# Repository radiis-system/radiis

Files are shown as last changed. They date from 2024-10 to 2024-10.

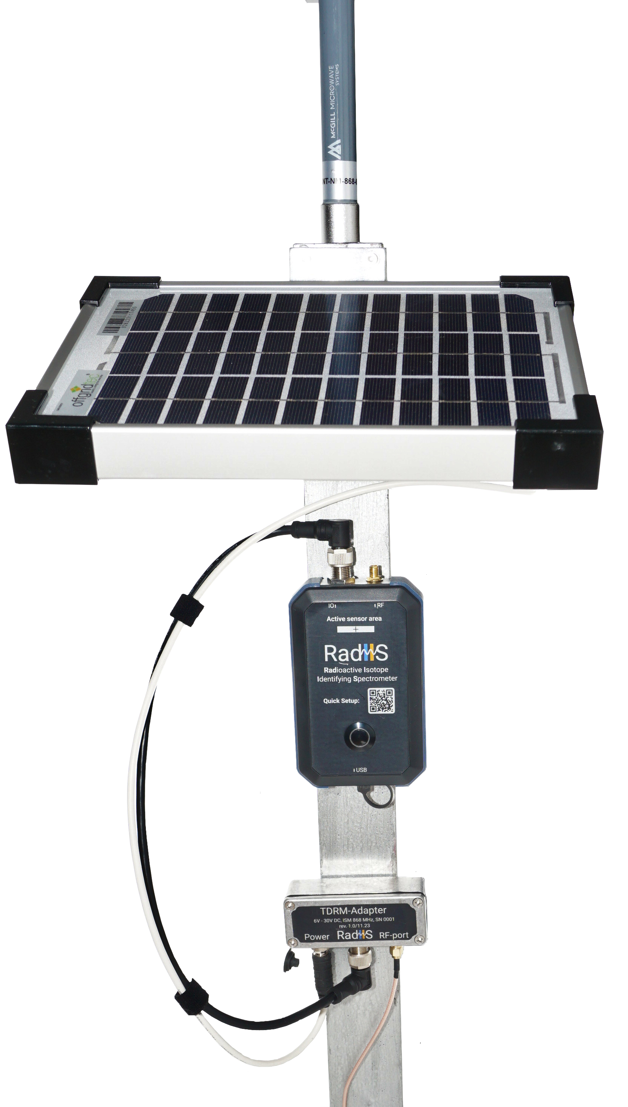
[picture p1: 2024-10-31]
Documentation/Pictures/RadIIS_Station.png

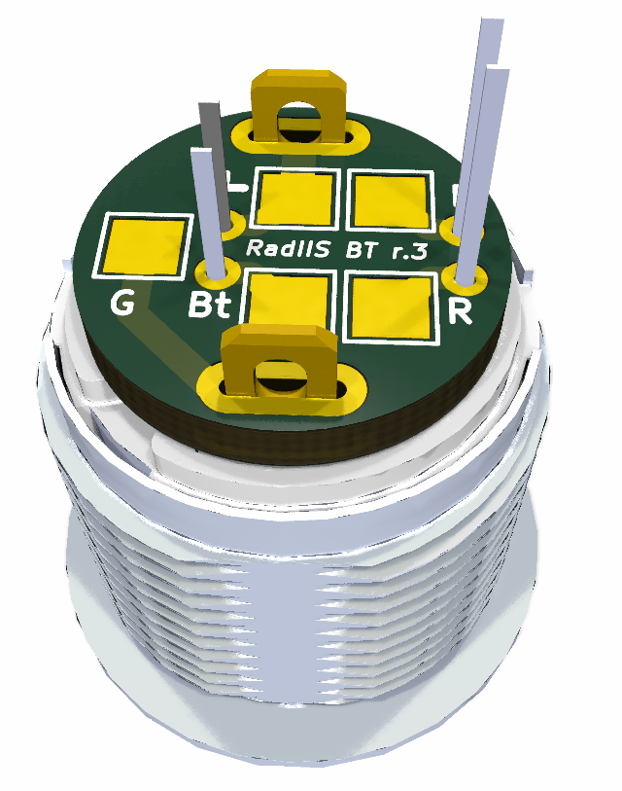
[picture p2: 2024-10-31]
Documentation/Pictures/BUTTON_PCB.png

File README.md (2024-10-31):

# RadIIS - the Radioactive Isotope Identifying Spectrometer

RadIIS is an open-source and industrial grade gamma spectrometer with automatic isotope identification.


It can be used as a handheld device, connected to a mobile phone (or tablet, pc, …) or as a monitoring station with backup battery, wide-range power input and long-range data transfer (LoRa).

> [!NOTE]
> This repository is currently transferred from a private repository. As different licenses for numerous files must be respected, this takes some time. Please stay tuned

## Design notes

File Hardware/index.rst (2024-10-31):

Hardware
==================================

documentation of the hardware side of RadIIS:

Mainboard
-----------

 `Mainboard BOM <../_static/ibom.html>`_

.. toctree::
   :maxdepth: 2
   :caption: Hardware:

    Hardware/index

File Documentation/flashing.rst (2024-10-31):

.. _flashing-label:

Programming
==================================

As RadIIS contains two microcontroller (STM32L476 and ESP32) the programming via USB is a two step process. Programming of the ESP32 is managed by the STM32 as this controller provides the USB interface.  

For all steps/methods RadIIS needs to be connected via USB to your (linux) computer. You need to be able to send SCPI commands to RadIIS (see :ref:`SCPI-label`).

Simple method (flashRadIIS.py)
-----------

.. TODO: Implement/Document the flashRadIIS.py

Use the provided flashRadIIS.py utility.

Direct programming STM32
-----------

1) Make sure the SCPI communication is working e.g. by requesting the device ID via ``*IDN?`` or check for connection via ``SYS:ACK?``
2) Reset the STM32 and enable the internal bootloader via ``SYStem:BOOTLoader``
3) Flash the firmware via dfu-util: ``dfu-util -a 0 -s 0x08000000:leave -D .pioenvs/RadIIS_STM/firmware.bin``

Direct programming ESP32
-----------

1) Make sure the SCPI communication is working e.g. by requesting the device ID via ``*IDN?`` or check for connection via ``SYS:ACK?``
2) Reset the ESP32, enable its bootloader and make route the USB communication to the ESP via the single command: ``SYStem:ESP:FLASHMode``
3) Flash the firmware via platform-io: ``pio run --target upload``

Internally platform-io uses esptool which can by also used to upload the firmware. 

The internal command is:

``python3 esptool.py --chip esp32 --port "/dev/ttyACM0" --baud 115200 --before default_reset --after hard_reset write_flash -z --flash_mode dio --flash_freq 40m --flash_size detect 0x1000 /home/<USER>/.platformio/packages/framework-arduinoespressif32/tools/sdk/bin/bootloader_dio_40m.bin 0x8000 <PROJECTDIR>/.pio/build/esp32dev/partitions.bin 0xe000 /home/<USER>/.platformio/packages/framework-arduinoespressif32/tools/partitions/boot_app0.bin 0x10000 <PROJECTDIR>/.pio/build/esp32dev/firmware.bin``

See https://docs.espressif.com/projects/esptool/en/latest/esp32/esptool/flashing-firmware.html for further details.

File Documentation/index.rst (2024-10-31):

(Advanced) Usage:
==================================

Advanced usage documentation, e.g. USB SCPI commands or firmware (re)flashing hints.
This part is meant for the advanced user that wishes to use the SCPI interface or to 
flash a custom firmware to the device.

.. toctree::
   :maxdepth: 1
   :caption: Usage:
   
   SCPI
   flashing

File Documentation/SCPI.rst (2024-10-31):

.. _SCPI-label:

SCPI commands
==================================

documentation of the (advanced) usage of RadIIS via SCPI Commands:

.. TODO: Document the connection and (working) serial tools

SYStem:BIAS
-----------
    
Set the SiPM bias, given in [mV]. Higher bias means a higher signal amplification. If a very low bias is set it might be impossible to digitize the signals. It is not possible to choose a bias that damages the system if the enclosure is intact.

The query, SYStem:BIAS?, returns the configured bias voltage in mV.

    | **Command Syntax:** ``SYStem:BIAS <int>``
    | **Parameters:** 24304 mV to 29950 mV
    | **Default:** 27000 mV
    | **Example:** ``SYS:BIAS 26000`` (Sets the bias to 26.00V)
    | **Query Syntax:** ``SYStem:BIAS?``
    | **Return Param:** SiPM bias in mV [int]

SYStem:ATC
-----------

Activates or deactivates the **A** utomatic **T** emperature **C** ompensation. If enabled the bias of the SiPM is automatically adjusted to maintain a constant gain during temperature variations. It is very recommended to acctivate the ATC during measurements.   

The query, SYStem:ATC?, returns the state if the ATC.

    | **Command Syntax:** ``SYStem:ATC <bool>``
    | **Parameters:** 0 (OFF) | 1 (ON)
    | **Default:** 1 (ON)
    | **Example:** ``SYS:ATC ON`` (Activates the ATC)
    | **Query Syntax:** ``SYStem:ATC?``
    | **Return Param:** State of the ATC [bool]

SYStem:TEMPerature?
-----------

Query the sensor (SiPM) temperature in mC.

    | **Query Syntax:** ``SYStem:TEMPerature?``
    | **Return Param:** SiPM temperature in mC [int]

SYStem:BATtery:LEVEL?
-----------
    
Query the internal battery level in mV [int].

    | **Query Syntax:** ``SYStem:BATtery:LEVEL?``
    | **Return Param:** Internal battery level in mV [int]
        
.. function:: SYStem:COMParator:THReshold <INT>
    
    Set the comparator threshold for the external and internal channel. The number is given in DAC counts. Higher numbers mean a higher signal level that is needed to trigger a detection of a pulse. 
    
    *Maximum = 4095*
    *Minimum = 0*
    *Default = 0*
    
    Example: SYS:COMP:THR 100 

.. function:: SYStem:COMParator:THReshold?
    
    *Returns:* Get the comparator threshold for the external and internal channel. [INT]

.. function:: SYStem:COMPerator:STate?
    
    *Returns:* Get the comparator state (enabled/disabled). [BOOL]

.. function:: SYStem:COMParator:STATE <BOOL>
    
    Enable/disable the comparator

    Example: SYS:COMP ON (Activates the comparator/trigger).

.. function:: SYStem:GATEtime <INT>
    
    Set the system gate time (time to measure the rates) in milliseconds

    *Default = 1000*
    
    Example: SYS:GATE 10000 
    
.. function:: SYStem:GATEtime?
    
    *Returns:* Get the system gate time. [INT]

.. function:: SYStem:Rate?
    
    *Returns:* Get the internal trigger rate in Hz (during the last full gate time). [INT]

.. function:: SYStem:EXRate?
    
    *Returns:* Get the external trigger rate in Hz (during the last full gate time). [INT]
   
.. function:: SYStem:BGRate?
    
    *Returns:* Get the internal background-corrected trigger rate in Hz (during the last full gate time). [INT]

.. function:: MEASurement:START <INT>,<INT>,<INT> 
    
    Start a measurement, arguments are:
    Runtime [ms], Maximum Counts, Channel
    
    Example: MEASurement:START 10000,100000,0 (Start a measurment with max. 10s duration, max. 100k counts using channel 0)

.. function:: MEASurement:STOP

    Stop all running measurements.

.. function:: MEASurement:STate?
    
    *Returns:* Get the current state of the measurement (running/idle) . [BOOL]

.. function:: MEASurement:GET?
    
    *Returns:* Transmit (current) the measurement result. [LIST]

.. function:: BACKGround:DATA:SET <BINARY BLOB>
    
    Set the background spectrum (not persistent, will be overwritten by ESP32!) 

    The binary data need to be formatted as following:
    channel0 = byte[0]+byte[1]<<8
    channel1 = byte[2]+byte[3]<<8
    ....
    channel511 = byte[1024]+byte[1025]<<8

    WARNING: The background function are not yet well tested

    Example: BACKG:DATA:SET <BINARY BLOB>

.. function:: BACKGround:DATA:GET?
    
    *Returns:* Transmit the curruntly configured background spectrum. [LIST]
	
    {
		.levels = {"BACKGround", "INFO","SET"},
		.params = {SCPI_DT_INT,SCPI_DT_INT,SCPI_DT_STRING},
		.callback = cmd_BACKG_INFO_SET_cb
	},

.. function:: BACKGround:INFO:GET?
    
    *Returns:* Get information about the currently configured background (Livetime, date, comment). [LIST]

.. function:: SYStem:BOOTLoader
    
    Reset the STM32 measurement controller into DFU bootloader mode for firmware flashing
    See :ref:`flashing-label` for more details.
	
.. function:: SYStem:ESP:FLASHMode
    
    Reset the ESP32 controller into bootloader mode for firmware flashing and relay the USB interface to the ESP.
    See :ref:`flashing-label` for more details.

.. function:: SYStem:ESP:TRANSMode
    
    Relay the USB interface to the ESP32. The interface is closed after 5s of inactivity.

.. function:: SYStem:ESP:Reset
    
    Reset the the ESP32. 

.. function:: SYStem:ESP:RTOFlashmode
    
    Reset the the ESP32 and boot the ESP32 into bootloader mode without starting the USB relay. 

.. function:: SYStem:DEBUGmode <BOOL>
    
    Disable or enable the Debug mode (higher verbosity)

    Example: SYS:DEBUG ON (Enable debug mode)

.. function:: SYStem:DEBUGmode?
    
    *Returns:* Get the state of the debug mode (higher verbosity). [BOOL]

.. function:: SYStem:ACKnowledge?
    
    *Returns:* Answer with "ACK" . [STRING]

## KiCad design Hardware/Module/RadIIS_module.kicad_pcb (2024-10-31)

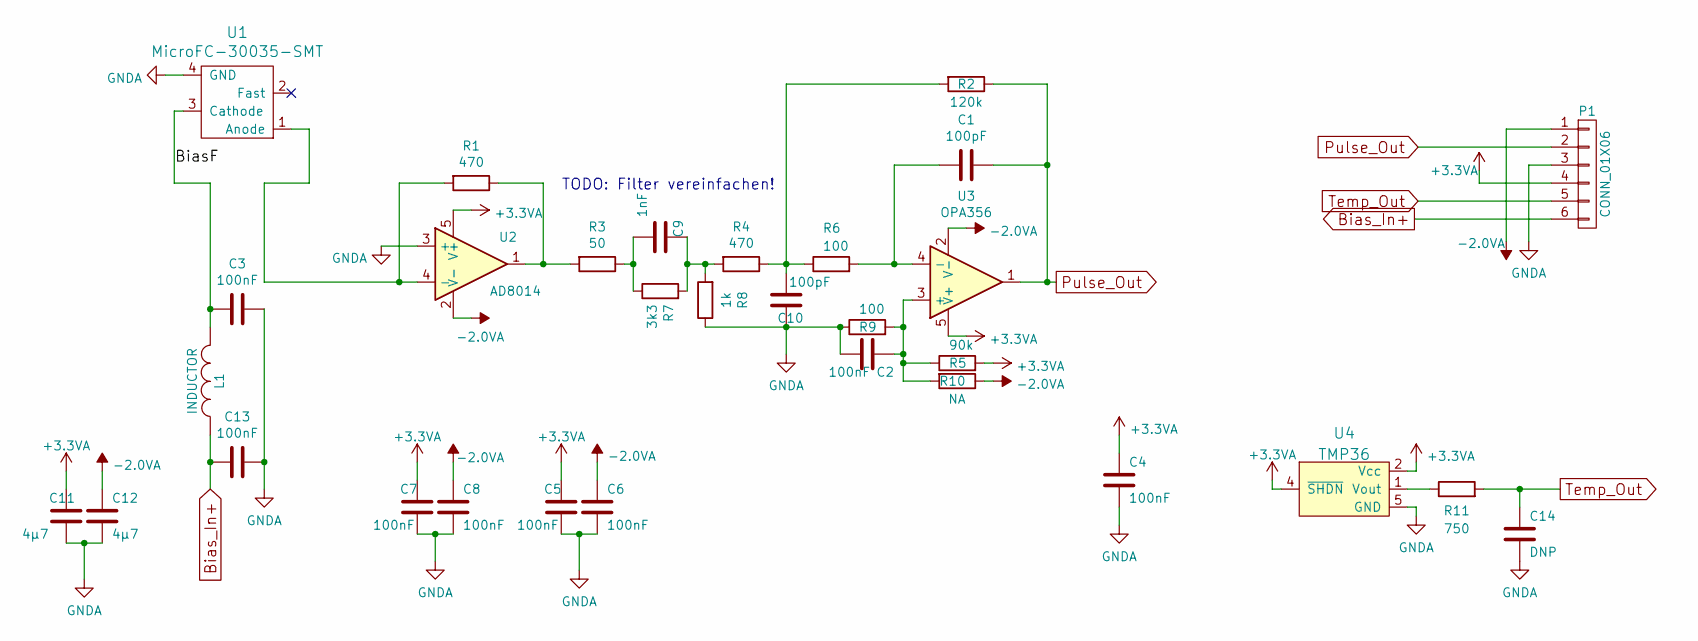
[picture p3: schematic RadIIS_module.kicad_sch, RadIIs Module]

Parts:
C1, C10: 100pF; C_0603_1608Metric; Digikey Nr 311-1069-1-ND
C2, C3, C4, C5, C6, C7, C8, C13: 100nF; C_0603_1608Metric; Digikey Nr 1292-1392-1-ND
C9: 1nF; C_0603_1608Metric; Digikey Nr 1292-1475-1-ND
C11, C12: 4µ7; C_1206_3216Metric; Digikey Nr 1276-3181-1-ND
C14: DNP; C_0603_1608Metric
L1: INDUCTOR; L_1206_3216Metric; Digikey Nr 240-2413-1-ND
P1: CONN_01X06; CardEdgeConnector; Digikey Nr NA
R1, R4: 470; R_0603_1608Metric; Digikey Nr 311-470HRCT-ND
R2: 120k; R_0603_1608Metric; Digikey Nr 311-120KHRCT-ND
R3: 50; R_0603_1608Metric; Digikey Nr 311-51.0HRCT-ND
R5: 90k; R_0603_1608Metric; Digikey Nr 311-90.9KHRCT-ND
R6, R9: 100; R_0603_1608Metric; Digikey Nr 311-100HRCT-ND
R7: 3k3; R_0603_1608Metric; Digikey Nr 311-3.30KHRCT-ND
R8: 1k; R_0603_1608Metric; Digikey Nr 311-1.00KHRCT-ND
R10: NA; R_0603_1608Metric; Digikey Nr NA
R11: 750; R_0603_1608Metric; Digikey Nr 311-100HRCT-ND
U1: MicroFC-30035-SMT; MicroFC-30035-SMT-C1; Digikey Nr MICROFC-30035-SMT-TR1OS-ND
U2: AD8014; SOT-23-5; Digikey Nr AD8014ARTZ-REEL7CT-ND
U3: OPA356; SOT-23-5; Digikey Nr 296-32191-1-ND
U4: TMP36; SOT-23-5; Digikey Nr TMP36GRTZ-REEL7CT-ND

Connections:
+3.3VA: C4.2, C5.2, C7.2, C11.2, P1.4, R5.2, U2.5 (V+), U3.5 (V+), U4.2 (Vcc), U4.4 (~SHDN)
-2.0VA: C6.2, C8.2, C12.2, P1.1, R10.1, U2.2 (V-), U3.2 (V-)
/BiasF: C3.2, L1.2, U1.3 (Cathode)
Bias_In+: C13.2, L1.1, P1.6
GNDA: C2.2, C3.1, C4.1, C5.1, C6.1, C7.1, C8.1, C10.2, C11.1, C12.1, C13.1, C14.1, P1.3, R8.1, R9.1, U1.4 (GND), U2.3 (+), U4.5 (GND)
unnamed: C1.2, R6.2, U3.4 (-)
unnamed: C2.1, R5.1, R9.2, R10.2, U3.3 (+)
unnamed: C9.1, R3.1, R7.1
unnamed: C9.2, R4.2, R7.2, R8.2
unnamed: C10.1, R2.2, R4.1, R6.1
unnamed: R1.1, R3.2, U2.1
unnamed: R1.2, U1.1 (Anode), U2.4 (-)
unnamed: R11.1, U4.1 (Vout)
Pulse_Out: C1.1, P1.2, R2.1, U3.1
Temp_Out: C14.2, P1.5, R11.2

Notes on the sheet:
TODO: Filter vereinfachen!

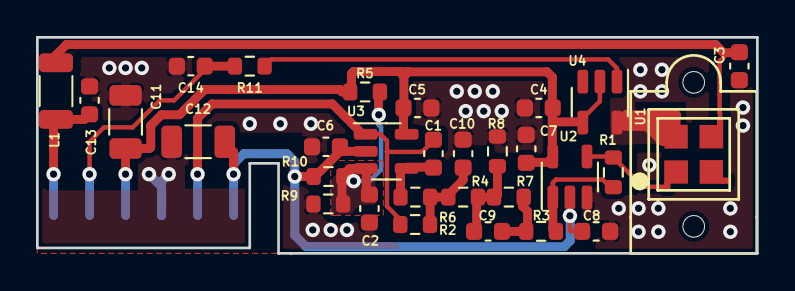
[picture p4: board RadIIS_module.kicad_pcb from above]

Board: 2 copper layers, 40.0 x 12.0 mm, 31 parts (1 on the bottom side), 15 nets.

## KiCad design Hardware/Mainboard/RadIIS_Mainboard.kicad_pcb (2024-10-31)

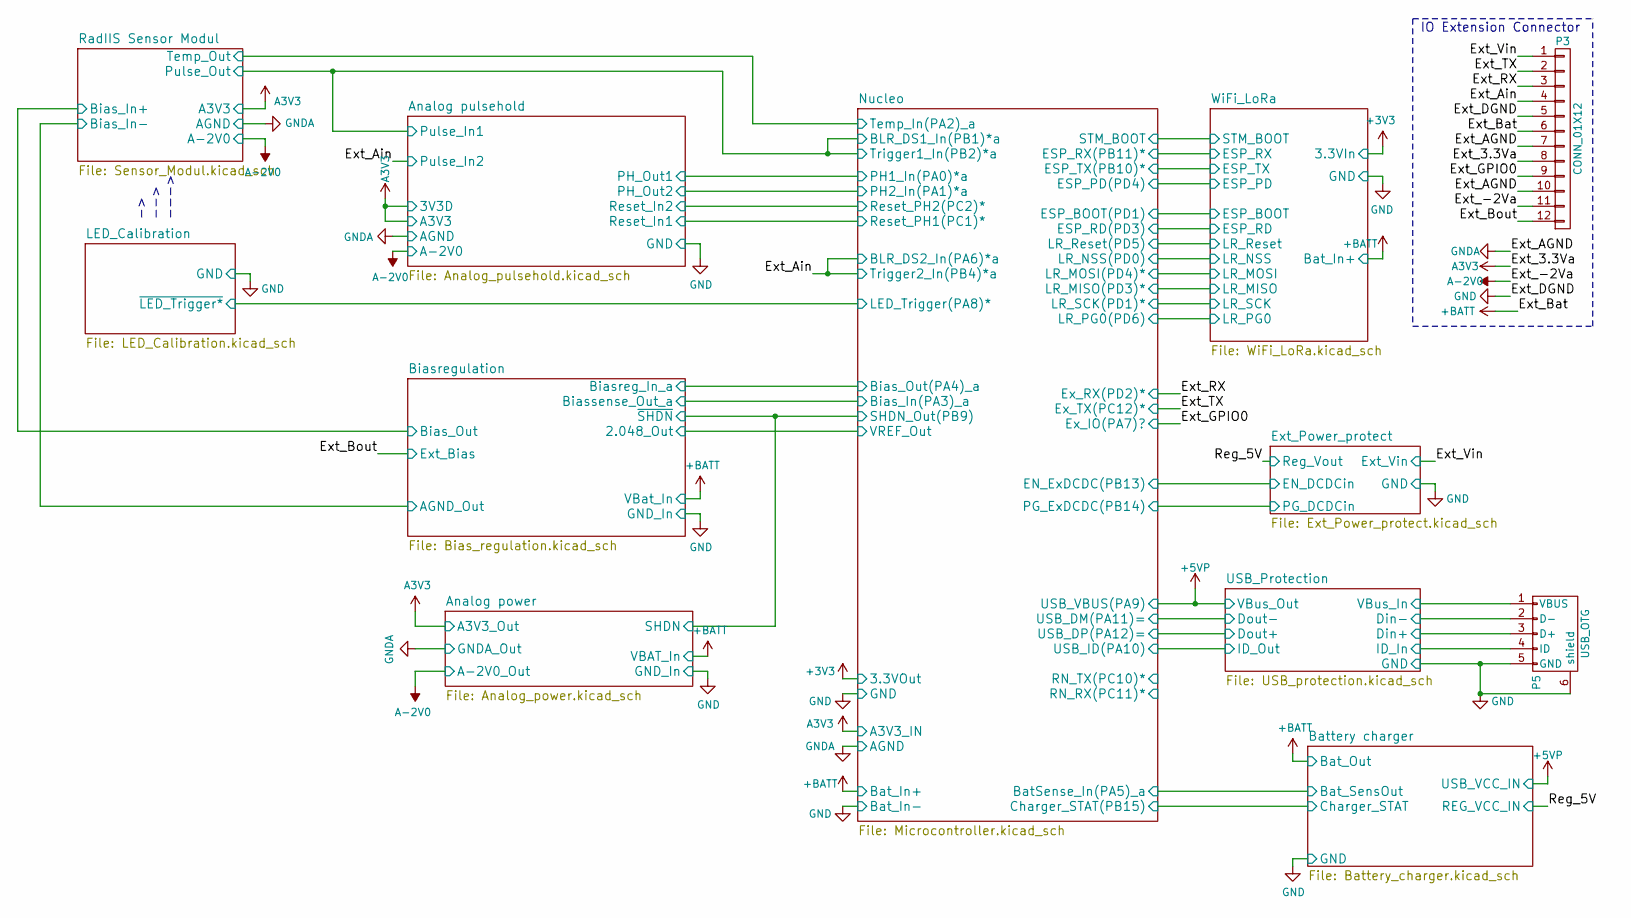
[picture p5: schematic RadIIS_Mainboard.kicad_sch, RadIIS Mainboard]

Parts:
P3: CONN_01X12; Hirose_FH12-12S-0.5SH_1x12-1MP_P0.50mm_Horizontal; Digikey Nr HFJ112CT-ND
P5: USB_OTG; MUSBK152XX; Digikey Nr MUSBK15230-ND

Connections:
+BATT: P3.6; also elsewhere on the board
/Ext_Ain: P3.4; also elsewhere on the board
/Ext_Bout: P3.12; also elsewhere on the board
/Ext_GPIO0: P3.9; also elsewhere on the board
/Ext_RX: P3.3; also elsewhere on the board
/Ext_TX: P3.2; also elsewhere on the board
/Ext_Vin: P3.1; also elsewhere on the board
/USB_Protection/Din+: P5.3 (D+); also elsewhere on the board
/USB_Protection/Din-: P5.2 (D-); also elsewhere on the board
/USB_Protection/ID_In: P5.4 (ID); also elsewhere on the board
/USB_Protection/VBus_In: P5.1 (VBUS); also elsewhere on the board
A3V3: P3.8; also elsewhere on the board
A-2V0: P3.11; also elsewhere on the board
GND: P3.5, P3.7, P3.10, P5.5 (GND), P5.6 (shield); also elsewhere on the board

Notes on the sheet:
IO Extension Connector
-> --> --->

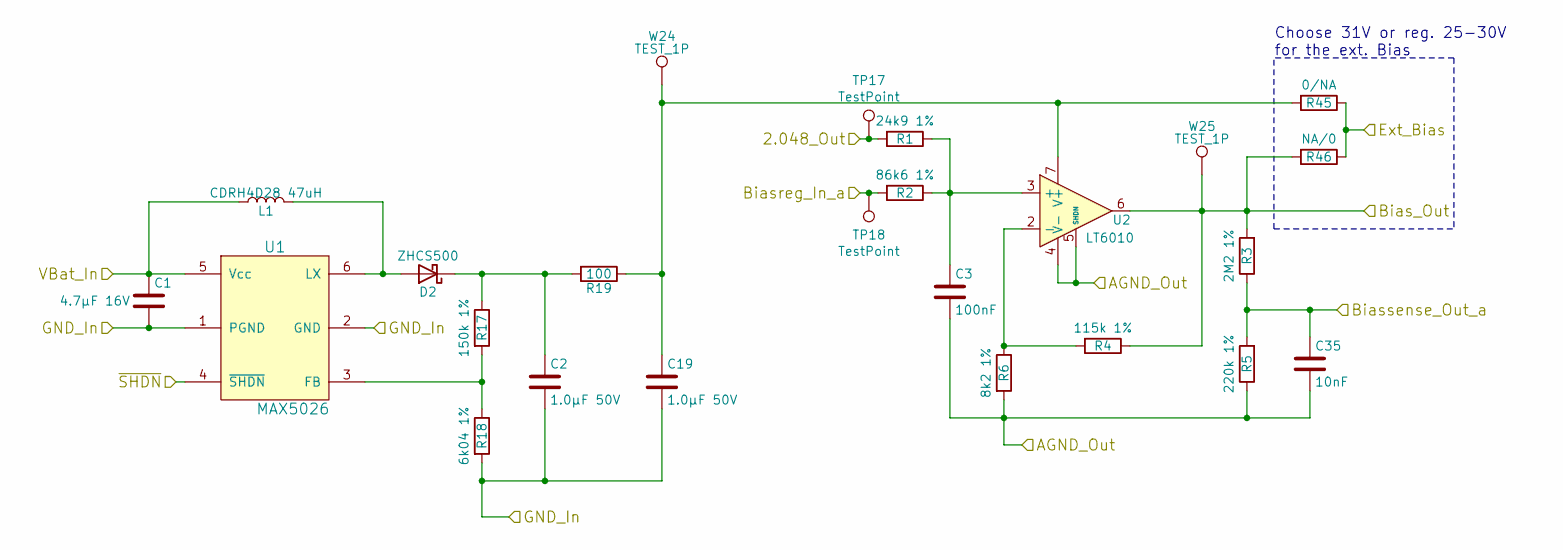
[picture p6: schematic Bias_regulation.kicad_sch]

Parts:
C1: 4.7µF 16V; C_0805_2012Metric; Digikey Nr 1276-1065-1-ND
C2, C19: 1.0µF 50V; C_0805_2012Metric; Digikey Nr 1276-6470-1-ND
C3: 100nF; C_0603_1608Metric; Digikey Nr 1276-1000-1-ND
C35: 10nF; C_0603_1608Metric; Digikey Nr 1276-1009-1-ND
D2: ZHCS500; D_SOT-23_ANK; Digikey Nr ZHCS500CT-ND
L1: CDRH4D28 47uH; CDRH4d28_FP; Digikey Nr 308-2182-1-ND
R1: 24k9 1%; R_0603_1608Metric; Digikey Nr 311-24.9KHRCT-ND
R2: 86k6 1%; R_0603_1608Metric; Digikey Nr 311-86.6KHRCT-ND
R3: 2M2 1%; R_0603_1608Metric; Digikey Nr YAG3329CT-ND
R4: 115k 1%; R_0603_1608Metric; Digikey Nr 311-115KHRCT-ND
R5: 220k 1%; R_0603_1608Metric; Digikey Nr 311-220KHRCT-ND
R6: 8k2 1%; R_0603_1608Metric; Digikey Nr 311-8.20KHRCT-ND
R17: 150k 1%; R_0603_1608Metric; Digikey Nr 311-150KHRCT-ND
R18: 6k04 1%; R_0603_1608Metric; Digikey Nr 311-150KHRCT-ND
R19: 100; R_0603_1608Metric; Digikey Nr 311-100HRCT-ND
R45: 0/NA; R_0603_1608Metric; Digikey Nr 311-0.0GRCT-ND
R46: NA/0; R_0603_1608Metric; Digikey Nr 311-0.0GRCT-ND
TP17, TP18: TestPoint; TestPoint_Pad_D1.5mm
U1: MAX5026; SOT-23-6; Digikey Nr MAX5026EUT+TCT-ND
U2: LT6010; SOIC-8_3.9x4.9mm_P1.27mm; Digikey Nr LT6010CS8#PBF-ND
W24, W25: TEST_1P; Socket_Strip_Straight_1x01_Pitch1.27mm; Digikey Nr NA

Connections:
+BATT: C1.1, L1.1, U1.5 (Vcc); also elsewhere on the board
/Analog power/SHDN: U1.4 (~SHDN); also elsewhere on the board
/Biasregulation/2.048_Out: R1.2, TP17.1; also elsewhere on the board
/Ext_Bout: R45.1, R46.1; also elsewhere on the board
/Nucleo/Bias_In(PA3)_a: C35.1, R3.1, R5.2; also elsewhere on the board
/Nucleo/Bias_Out(PA4)_a: R2.2, TP18.1; also elsewhere on the board
/RadIIS Sensor Modul/Bias_In+: R3.2, R4.1, R46.2, U2.6, W25.1; also elsewhere on the board
GND: C1.2, C2.2, C3.2, C19.2, C35.2, R5.1, R6.2, R18.2, U1.1 (PGND), U1.2 (GND), U2.4 (V-), U2.5 (SHDN); also elsewhere on the board
unnamed: C2.1, D2.1 (K), R17.1, R19.2
unnamed: C3.1, R1.1, R2.1, U2.3 (+)
unnamed: C19.1, R19.1, R45.2, U2.7 (V+), W24.1
unnamed: D2.2 (A), L1.2, U1.6 (LX)
unnamed: R4.2, R6.1, U2.2 (-)
unnamed: R17.2, R18.1, U1.3 (FB)

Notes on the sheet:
Choose 31V or reg. 25-30V for the ext. Bias

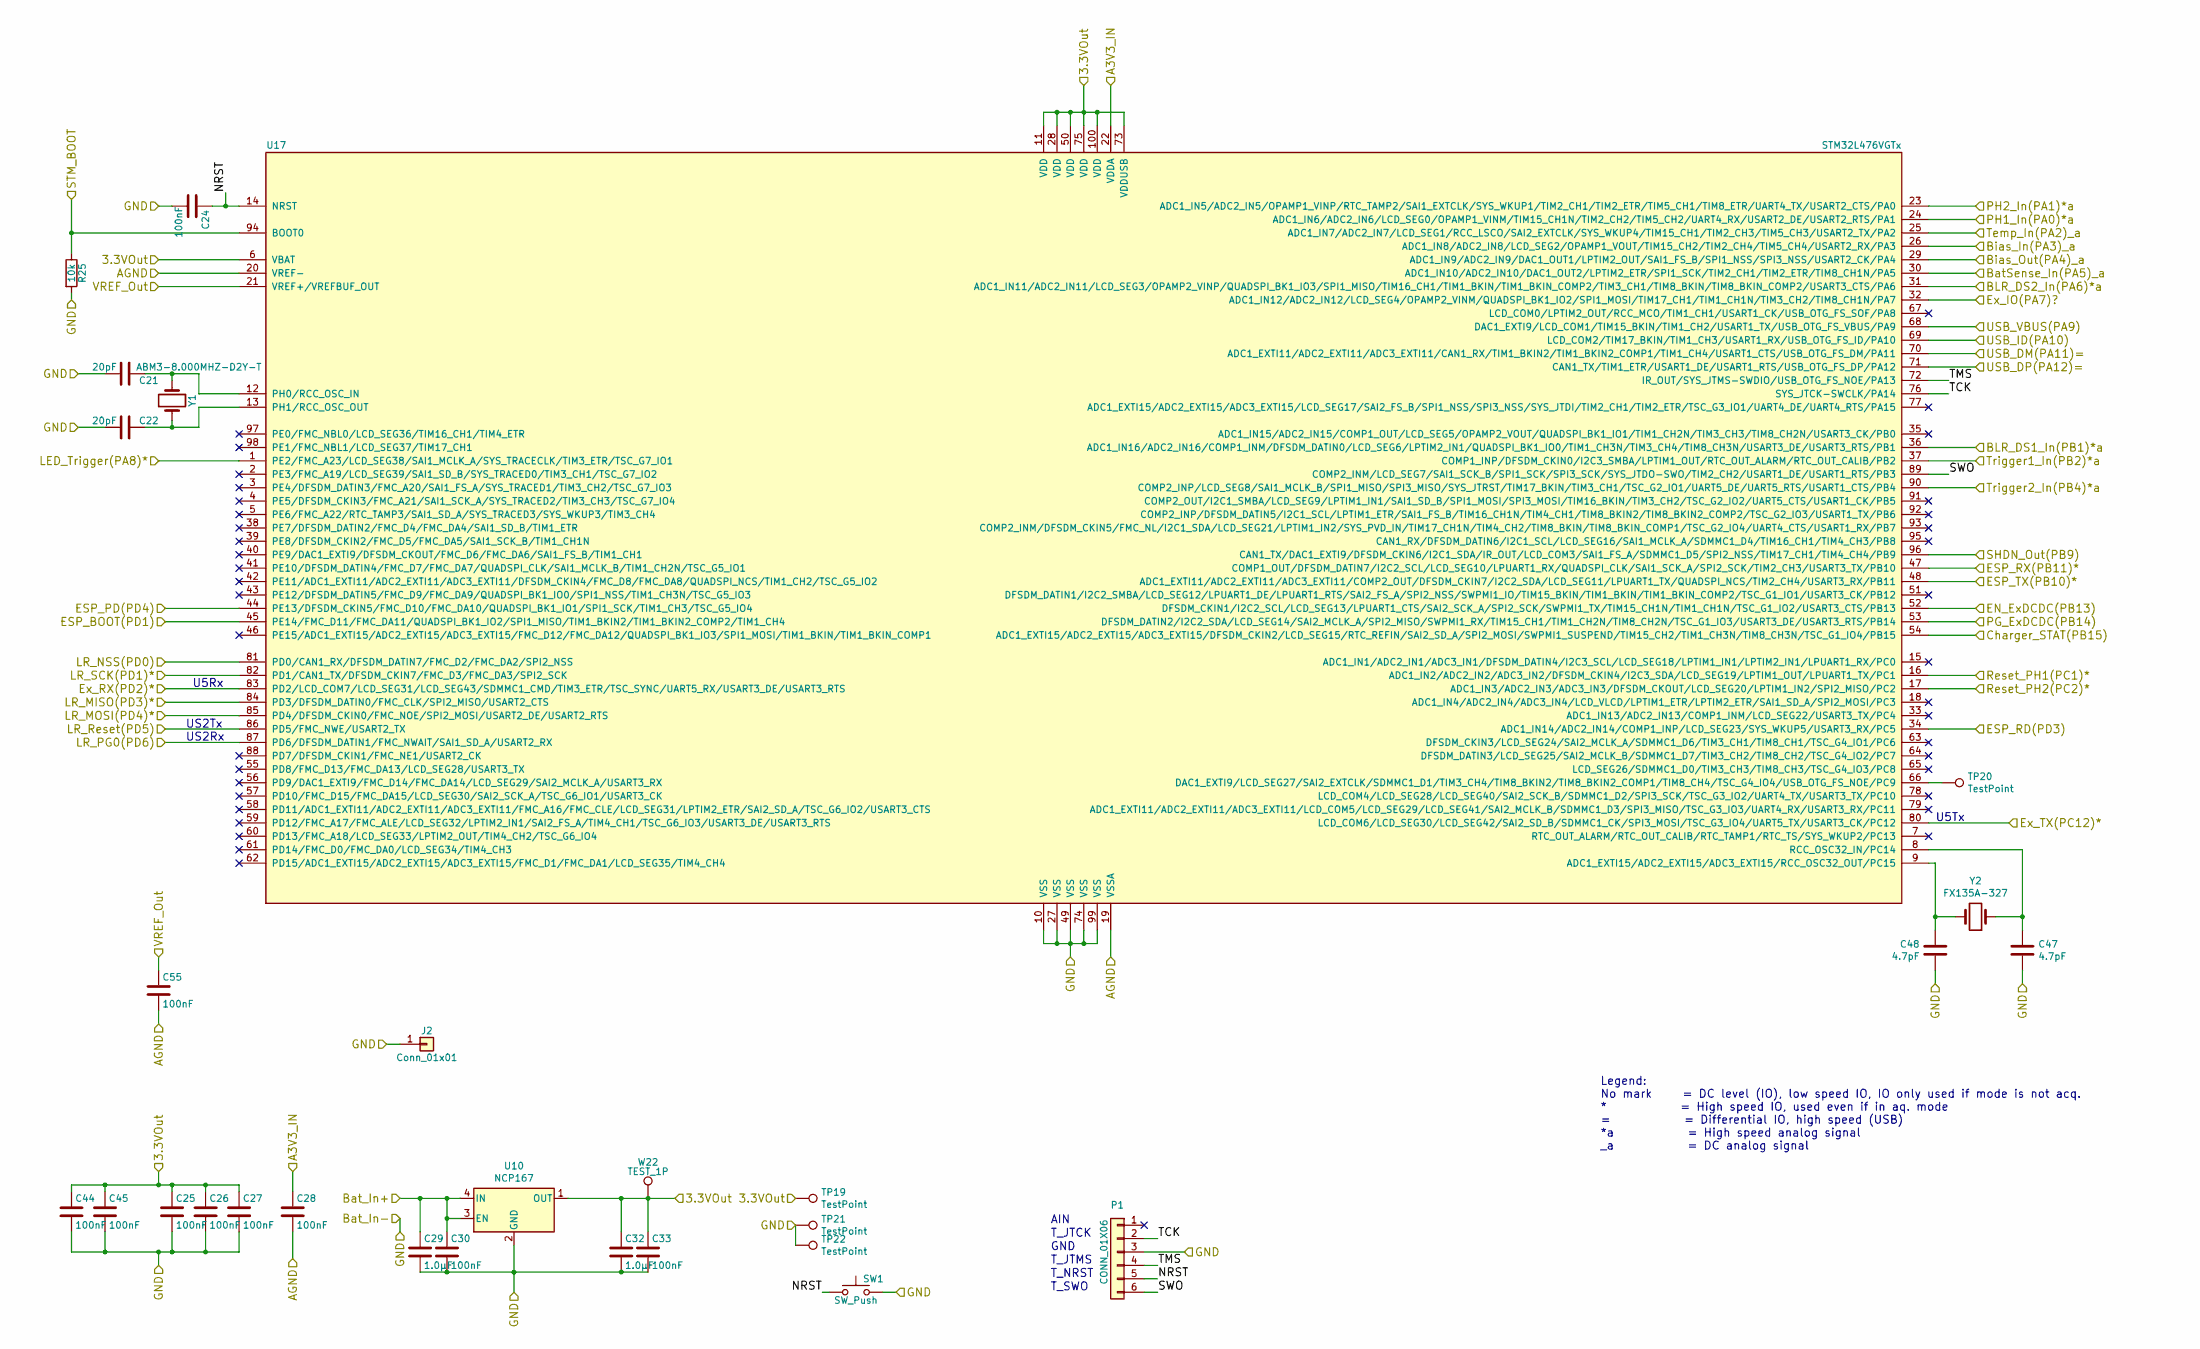
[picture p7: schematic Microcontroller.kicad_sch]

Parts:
C21, C22: 20pF; C_0603_1608Metric; Digikey Nr 1276-1187-1-ND
C24, C25, C26, C27, C28, C30, C33, C44, C45, C55: 100nF; C_0603_1608Metric; Digikey Nr 1276-1000-1-ND
C29, C32: 1.0µF; C_0805_2012Metric; Digikey Nr 1276-2931-1-ND
C47, C48: 4.7pF; C_0603_1608Metric; Digikey Nr 311-1740-1-ND
J2: Conn_01x01; PinHeader_1x01_P1.27mm_Vertical; Digikey Nr NA
P1: CONN_01X06; Pin_Header_Straight_1x06_Pitch1.27mm; Digikey Nr NA
R25: 10k; R_0603_1608Metric; Digikey Nr 311-10.0KHRCT-ND
SW1: SW_Push; SW_SPST_PTS810; Digikey Nr CKN10503CT-ND
TP19, TP20, TP21, TP22: TestPoint; TestPoint_Pad_D1.5mm
U10: NCP167; XDFN4
U17: STM32L476VGTx; LQFP-100_14x14mm_P0.5mm; Digikey Nr 497-15873-ND
W22: TEST_1P; Measurement_Point_Round-SMD-Pad_Small; Digikey Nr NA
Y1: ABM3-8.000MHZ-D2Y-T; Crystal_SMD_Abracon_ABM3-2Pin_5.0x3.2mm; Digikey Nr 535-10630-1-ND
Y2: FX135A-327; Crystal_SMD_G8-2Pin_3.2x1.5mm; Digikey Nr 631-1002-1-ND

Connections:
+3V3: C25.1, C26.1, C27.1, C32.1, C33.1, C44.1, C45.1, TP19.1, U10.1 (OUT), U17.6 (VBAT), U17.11 (VDD), U17.28 (VDD), U17.50 (VDD), U17.73 (VDDUSB), U17.75 (VDD), U17.100 (VDD), W22.1; also elsewhere on the board
+5VP: U17.68 (DAC1_EXTI9/LCD_COM1/TIM15_BKIN/TIM1_CH2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); also elsewhere on the board
+BATT: C29.1, C30.1, U10.3 (EN), U10.4 (IN); also elsewhere on the board
/Analog power/SHDN: U17.96 (CAN1_TX/DAC1_EXTI9/DFSDM_CKIN6/I2C1_SDA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); also elsewhere on the board
/Analog pulsehold/Reset_In1: U17.16 (ADC1_IN2/ADC2_IN2/ADC3_IN2/DFSDM_CKIN4/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); also elsewhere on the board
/Analog pulsehold/Reset_In2: U17.17 (ADC1_IN3/ADC2_IN3/ADC3_IN3/DFSDM_CKOUT/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); also elsewhere on the board
/Battery charger/Charger_STAT: U17.54 (ADC1_EXTI15/ADC2_EXTI15/ADC3_EXTI15/DFS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); also elsewhere on the board
/Biasregulation/2.048_Out: C55.1, U17.21 (VREF+/VREFBUF_OUT); also elsewhere on the board
/Ext_Ain: U17.31 (ADC1_IN11/ADC2_IN11/LCD_SEG3/OPAMP2_VIN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), U17.90 (COMP2_INP/LCD_SEG8/SAI1_MCLK_B/SPI1_MIS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); also elsewhere on the board
/Ext_GPIO0: U17.32 (ADC1_IN12/ADC2_IN12/LCD_SEG4/OPAMP2_VIN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); also elsewhere on the board
/Ext_Power_protect/EN_DCDCin: U17.52 (DFSDM_CKIN1/I2C2_SCL/LCD_SEG13/LPUART1_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); also elsewhere on the board
/Ext_Power_protect/PG_DCDCin: U17.53 (DFSDM_DATIN2/I2C2_SDA/LCD_SEG14/SAI2_MC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); also elsewhere on the board
/Ext_RX: U17.83 (PD2/LCD_COM7/LCD_SEG31/LCD_SEG43/SDMMC1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); also elsewhere on the board
/Ext_TX: U17.80 (LCD_COM6/LCD_SEG30/LCD_SEG42/SAI2_SD_B/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); also elsewhere on the board
/Nucleo/BLR_DS1_In(PB1)*a: U17.36 (ADC1_IN16/ADC2_IN16/COMP1_INM/DFSDM_DAT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), U17.37 (COMP1_INP/DFSDM_CKIN0/I2C3_SMBA/LPTIM1_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); also elsewhere on the board
/Nucleo/BatSense_In(PA5)_a: U17.30 (ADC1_IN10/ADC2_IN10/DAC1_OUT2/LPTIM2_ET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); also elsewhere on the board
/Nucleo/Bias_In(PA3)_a: U17.26 (ADC1_IN8/ADC2_IN8/LCD_SEG2/OPAMP1_VOUT/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); also elsewhere on the board
/Nucleo/Bias_Out(PA4)_a: U17.29 (ADC1_IN9/ADC2_IN9/DAC1_OUT1/LPTIM2_OUT/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); also elsewhere on the board
/Nucleo/LED_Trigger(PA8)*: U17.1 (PE2/FMC_A23/LCD_SEG38/SAI1_MCLK_A/SYS_T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); also elsewhere on the board
/Nucleo/NRST: C24.1, P1.5, SW1.1, U17.14 (NRST)
/Nucleo/PH1_In(PA0)*a: U17.24 (ADC1_IN6/ADC2_IN6/LCD_SEG0/OPAMP1_VINM/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); also elsewhere on the board
/Nucleo/PH2_In(PA1)*a: U17.23 (ADC1_IN5/ADC2_IN5/OPAMP1_VINP/RTC_TAMP2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); also elsewhere on the board
/Nucleo/STM_BOOT: R25.1, U17.94 (BOOT0); also elsewhere on the board
/Nucleo/SWO: P1.6, U17.89 (COMP2_INM/LCD_SEG7/SAI1_SCK_B/SPI1_SCK/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)
/Nucleo/TCK: P1.2, U17.76 (SYS_JTCK-SWCLK/PA14)
/Nucleo/TMS: P1.4, U17.72 (IR_OUT/SYS_JTMS-SWDIO/USB_OTG_FS_NOE/PA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)
/Nucleo/Temp_In(PA2)_a: U17.25 (ADC1_IN7/ADC2_IN7/LCD_SEG1/RCC_LSCO/SAI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); also elsewhere on the board
/USB_Protection/Dout+: U17.71 (CAN1_TX/TIM1_ETR/USART1_DE/USART1_RTS/U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); also elsewhere on the board
/USB_Protection/Dout-: U17.70 (ADC1_EXTI11/ADC2_EXTI11/ADC3_EXTI11/CAN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); also elsewhere on the board
/USB_Protection/ID_In: U17.69 (LCD_COM2/TIM17_BKIN/TIM1_CH3/USART1_RX/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); also elsewhere on the board
/WiFi_LoRa/ESP_BOOT: U17.45 (PE14/FMC_D11/FMC_DA11/QUADSPI_BK1_IO2/S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); also elsewhere on the board
/WiFi_LoRa/ESP_PD: U17.44 (PE13/DFSDM_CKIN5/FMC_D10/FMC_DA10/QUADS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); also elsewhere on the board
/WiFi_LoRa/ESP_RD: U17.34 (ADC1_IN14/ADC2_IN14/COMP1_INP/LCD_SEG23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); also elsewhere on the board
/WiFi_LoRa/ESP_RX: U17.47 (COMP1_OUT/DFSDM_DATIN7/I2C2_SCL/LCD_SEG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); also elsewhere on the board
/WiFi_LoRa/ESP_TX: U17.48 (ADC1_EXTI11/ADC2_EXTI11/ADC3_EXTI11/COM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); also elsewhere on the board
/WiFi_LoRa/LR_MISO: U17.84 (PD3/DFSDM_DATIN0/FMC_CLK/SPI2_MISO/USAR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); also elsewhere on the board
/WiFi_LoRa/LR_MOSI: U17.85 (PD4/DFSDM_CKIN0/FMC_NOE/SPI2_MOSI/USART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); also elsewhere on the board
/WiFi_LoRa/LR_NSS: U17.81 (PD0/CAN1_RX/DFSDM_DATIN7/FMC_D2/FMC_DA2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); also elsewhere on the board
/WiFi_LoRa/LR_PG0: U17.87 (PD6/DFSDM_DATIN1/FMC_NWAIT/SAI1_SD_A/US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); also elsewhere on the board
/WiFi_LoRa/LR_Reset: U17.86 (PD5/FMC_NWE/USART2_TX); also elsewhere on the board
/WiFi_LoRa/LR_SCK: U17.82 (PD1/CAN1_TX/DFSDM_CKIN7/FMC_D3/FMC_DA3/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); also elsewhere on the board
A3V3: C28.1, U17.22 (VDDA); also elsewhere on the board
GND: C21.2, C22.2, C24.2, C25.2, C26.2, C27.2, C28.2, C29.2, C30.2, C32.2, C33.2, C44.2, C45.2, C47.2, C48.2, C55.2, J2.1, P1.3, R25.2, SW1.2, TP21.1, TP22.1, U10.2 (GND), U10.EPAD (GND), U17.10 (VSS), U17.19 (VSSA), U17.20 (VREF-), U17.27 (VSS), U17.49 (VSS), U17.74 (VSS), U17.99 (VSS); also elsewhere on the board
unnamed: C21.1, U17.12 (PH0/RCC_OSC_IN), Y1.1
unnamed: C22.1, U17.13 (PH1/RCC_OSC_OUT), Y1.2
unnamed: C47.1, U17.8 (RCC_OSC32_IN/PC14), Y2.1
unnamed: C48.1, U17.9 (ADC1_EXTI15/ADC2_EXTI15/ADC3_EXTI15/RCC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), Y2.2
unnamed: TP20.1, U17.66 (DAC1_EXTI9/LCD_SEG27/SAI2_EXTCLK/SDMMC1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)

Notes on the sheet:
T_JTMS
U5Tx
AIN
Legend: No mark = DC level (IO), low speed IO, IO only used if mode is not acq. * = High speed IO, used even if in aq. mode = = Differential IO, high speed (USB) *a = High speed analog signal _a = DC analog signal
US2Tx US2Rx
U5Rx
GND
T_JTCK
T_NRST
T_SWO

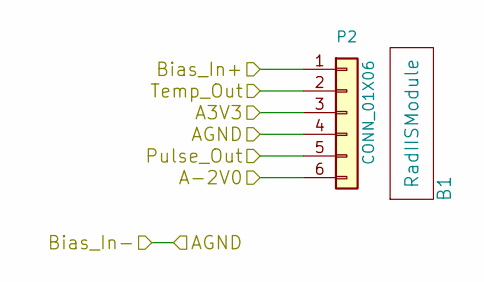
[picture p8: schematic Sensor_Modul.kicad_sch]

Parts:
B1: RadIISModule; Digikey Nr NA
P2: CONN_01X06; 6Pin_CardEdge_CON; Digikey Nr 581-009159006551906

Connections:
/Nucleo/BLR_DS1_In(PB1)*a: P2.5; also elsewhere on the board
/Nucleo/Temp_In(PA2)_a: P2.2; also elsewhere on the board
/RadIIS Sensor Modul/Bias_In+: P2.1; also elsewhere on the board
A3V3: P2.3; also elsewhere on the board
A-2V0: P2.6; also elsewhere on the board
GND: P2.4; also elsewhere on the board

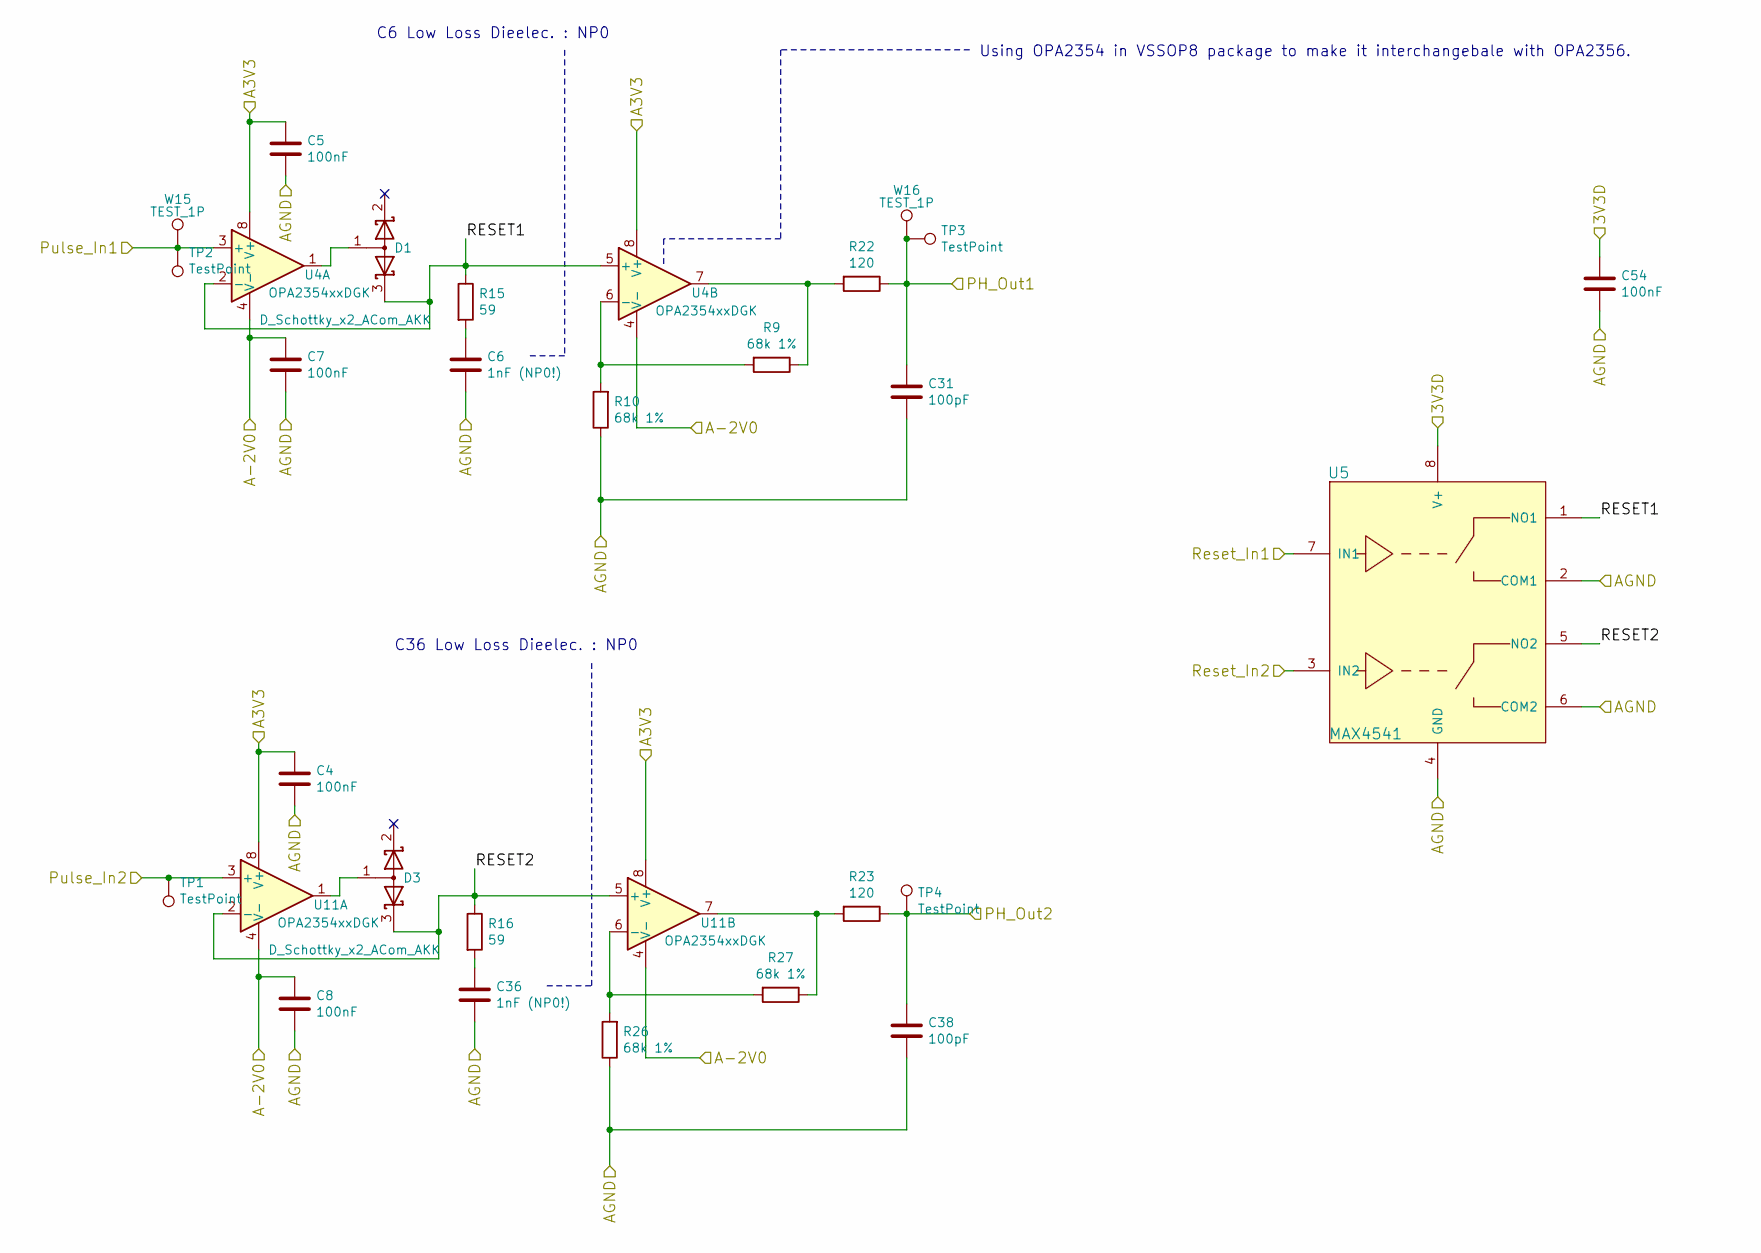
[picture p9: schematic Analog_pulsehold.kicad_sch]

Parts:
C4, C5, C7, C8, C54: 100nF; C_0603_1608Metric; Digikey Nr 1276-1000-1-ND
C6, C36: 1nF (NP0!); C_0603_1608Metric; Digikey Nr 1292-1475-1-ND
C31, C38: 100pF; C_0603_1608Metric; Digikey Nr 311-1069-1-ND
D1, D3: D_Schottky_x2_ACom_AKK; SOT-23; Digikey Nr MMBD301LT1GOSCT-ND
R9, R10, R26, R27: 68k 1%; R_0603_1608Metric; Digikey Nr 311-68.0KHRCT-ND
R15, R16: 59; R_0603_1608Metric; Digikey Nr 311-59.0HRCT-ND
R22, R23: 120; R_0603_1608Metric; Digikey Nr 311-120HRCT-ND
TP1, TP2, TP3, TP4: TestPoint; TestPoint_Pad_D1.5mm
U4, U11: OPA2354xxDGK; VSSOP-8_3.0x3.0mm_P0.65mm; Digikey Nr 296-12642-1-ND
U5: MAX4541; uMAX8; Digikey Nr MAX4541EUA+-ND
W15, W16: TEST_1P; Measurement_Point_Round-SMD-Pad_Small; Digikey Nr NA

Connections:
/Analog pulsehold/RESET1: D1.3 (K), R15.1, U4.2 (-), U4.5 (+), U5.1 (NO1)
/Analog pulsehold/RESET2: D3.3 (K), R16.1, U5.5 (NO2), U11.2 (-), U11.5 (+)
/Analog pulsehold/Reset_In1: U5.7 (IN1); also elsewhere on the board
/Analog pulsehold/Reset_In2: U5.3 (IN2); also elsewhere on the board
/Ext_Ain: TP1.1, U11.3 (+); also elsewhere on the board
/Nucleo/BLR_DS1_In(PB1)*a: TP2.1, U4.3 (+), W15.1; also elsewhere on the board
/Nucleo/PH1_In(PA0)*a: C31.1, R22.1, TP3.1, W16.1; also elsewhere on the board
/Nucleo/PH2_In(PA1)*a: C38.1, R23.1, TP4.1; also elsewhere on the board
A3V3: C4.1, C5.1, C54.1, U4.8 (V+), U5.8 (V+), U11.8 (V+); also elsewhere on the board
A-2V0: C7.2, C8.1, U4.4 (V-), U11.4 (V-); also elsewhere on the board
GND: C4.2, C5.2, C6.2, C7.1, C8.2, C31.2, C36.2, C38.2, C54.2, R10.1, R26.1, U5.2 (COM1), U5.4 (GND), U5.6 (COM2); also elsewhere on the board
unnamed: C6.1, R15.2
unnamed: C36.1, R16.2
unnamed: D1.1 (A), U4.1
unnamed: D3.1 (A), U11.1
unnamed: R9.2, R10.2, U4.6 (-)
unnamed: R9.1, R22.2, U4.7
unnamed: R23.2, R27.1, U11.7
unnamed: R26.2, R27.2, U11.6 (-)

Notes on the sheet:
C36 Low Loss Dieelec. : NP0
C6 Low Loss Dieelec. : NP0
Using OPA2354 in VSSOP8 package to make it interchangebale with OPA2356.

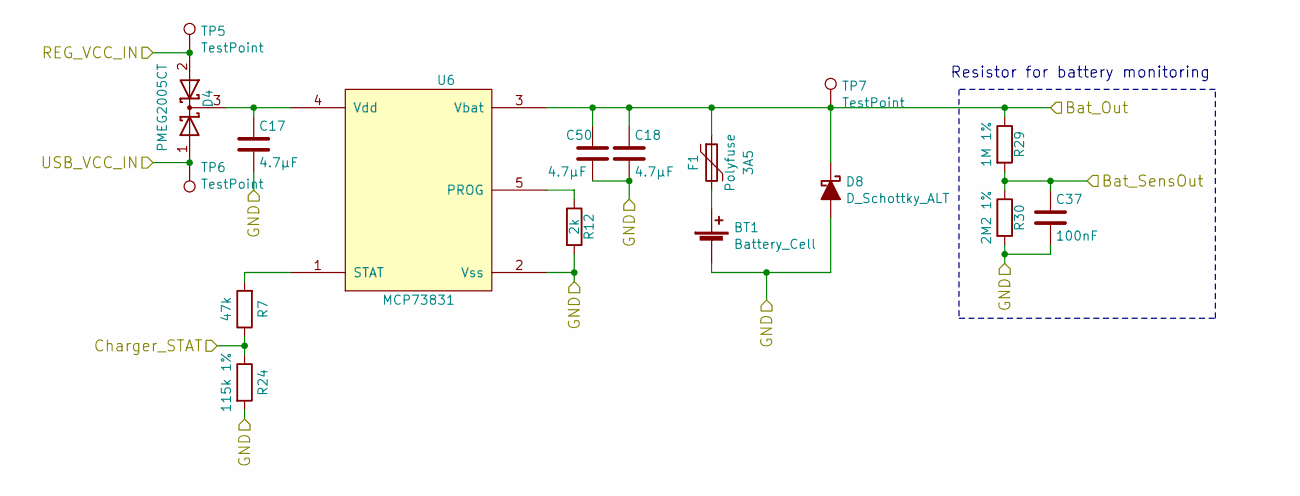
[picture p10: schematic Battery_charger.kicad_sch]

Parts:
BT1: Battery_Cell; PinHeader_1x02_P2.54mm_Vertical; Digikey Nr NA
C17, C18, C50: 4.7µF; C_0805_2012Metric; Digikey Nr 1276-1065-1-ND
C37: 100nF; C_0603_1608Metric; Digikey Nr 1276-1000-1-ND
D4: PMEG2005CT; SOT-23; Digikey Nr 1727-5188-1-ND
D8: D_Schottky_ALT; D_SOD-123F; Digikey Nr MBR230LSFT1GOSCT-ND
F1: Polyfuse; Fuse_1206_3216Metric; Digikey Nr MF-NSML175-2CT-ND
R7: 47k; R_0603_1608Metric; Digikey Nr 311-47.0KHRCT-ND
R12: 2k; R_0603_1608Metric; Digikey Nr 311-2.00KHRCT-ND
R24: 115k 1%; R_0603_1608Metric; Digikey Nr 311-115KHRCT-ND
R29: 1M 1%; R_0603_1608Metric; Digikey Nr 311-1.00MHRCT-ND
R30: 2M2 1%; R_0603_1608Metric; Digikey Nr YAG3329CT-ND
TP5, TP6, TP7: TestPoint; TestPoint_Pad_D1.5mm
U6: MCP73831; SOT-23-5; Digikey Nr MCP73831T-2ACI/OTCT-ND

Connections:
+5VP: D4.1 (A), TP6.1; also elsewhere on the board
+BATT: C18.1, C50.1, D8.1 (K), F1.1, R29.1, TP7.1, U6.3 (Vbat); also elsewhere on the board
/Battery charger/Charger_STAT: R7.1, R24.1; also elsewhere on the board
/Nucleo/BatSense_In(PA5)_a: C37.1, R29.2, R30.1; also elsewhere on the board
/Reg_5V: D4.2 (A), TP5.1; also elsewhere on the board
GND: BT1.2 (-), C17.2, C18.2, C37.2, C50.2, D8.2 (A), R12.2, R24.2, R30.2, U6.2 (Vss); also elsewhere on the board
unnamed: BT1.1 (+), F1.2
unnamed: C17.1, D4.3 (K), U6.4 (Vdd)
unnamed: R7.2, U6.1 (STAT)
unnamed: R12.1, U6.5 (PROG)

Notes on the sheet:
Resistor for battery monitoring

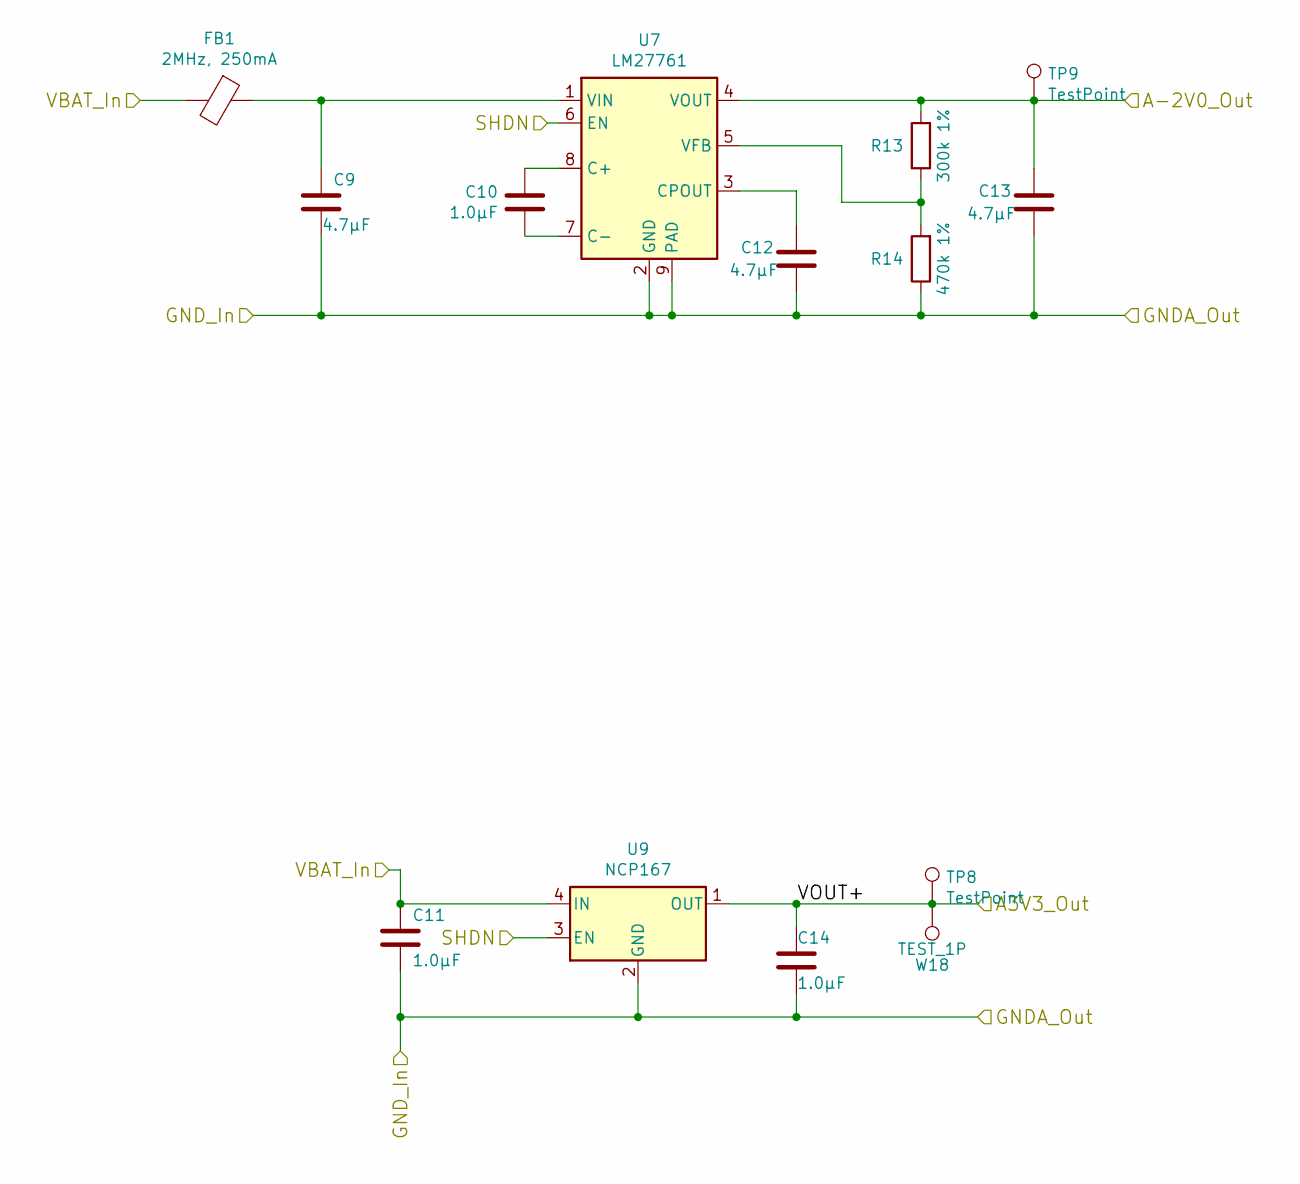
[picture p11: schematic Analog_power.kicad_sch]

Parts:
C9, C12, C13: 4.7µF; C_0805_2012Metric; Digikey Nr 1276-1065-1-ND
C10, C11, C14: 1.0µF; C_0805_2012Metric; Digikey Nr 1276-2931-1-ND
FB1: 2MHz, 250mA; L_0603_1608Metric; Digikey Nr 445-8694-1-ND
R13: 300k 1%; R_0603_1608Metric; Digikey Nr 311-300KHRCT-ND
R14: 470k 1%; R_0603_1608Metric; Digikey Nr 311-470KHRCT-ND
TP8, TP9: TestPoint; TestPoint_Pad_D1.5mm
U7: LM27761; WSON-8-1EP_2x2mm_P0.5mm_EP0.9x1.6mm; Digikey Nr 296-44379-1-ND
U9: NCP167; XDFN4
W18: TEST_1P; Measurement_Point_Round-SMD-Pad_Small; Digikey Nr NA

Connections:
+BATT: C11.1, FB1.2, U9.4 (IN); also elsewhere on the board
/Analog power/SHDN: U7.6 (EN), U9.3 (EN); also elsewhere on the board
A3V3: C14.1, TP8.1, U9.1 (OUT), W18.1; also elsewhere on the board
A-2V0: C13.1, R13.2, TP9.1, U7.4 (VOUT); also elsewhere on the board
GND: C9.2, C11.2, C12.2, C13.2, C14.2, R14.1, U7.2 (GND), U7.9 (PAD), U9.2 (GND), U9.EPAD (GND); also elsewhere on the board
unnamed: C9.1, FB1.1, U7.1 (VIN)
unnamed: C10.1, U7.8 (C+)
unnamed: C10.2, U7.7 (C-)
unnamed: C12.1, U7.3 (CPOUT)
unnamed: R13.1, R14.2, U7.5 (VFB)

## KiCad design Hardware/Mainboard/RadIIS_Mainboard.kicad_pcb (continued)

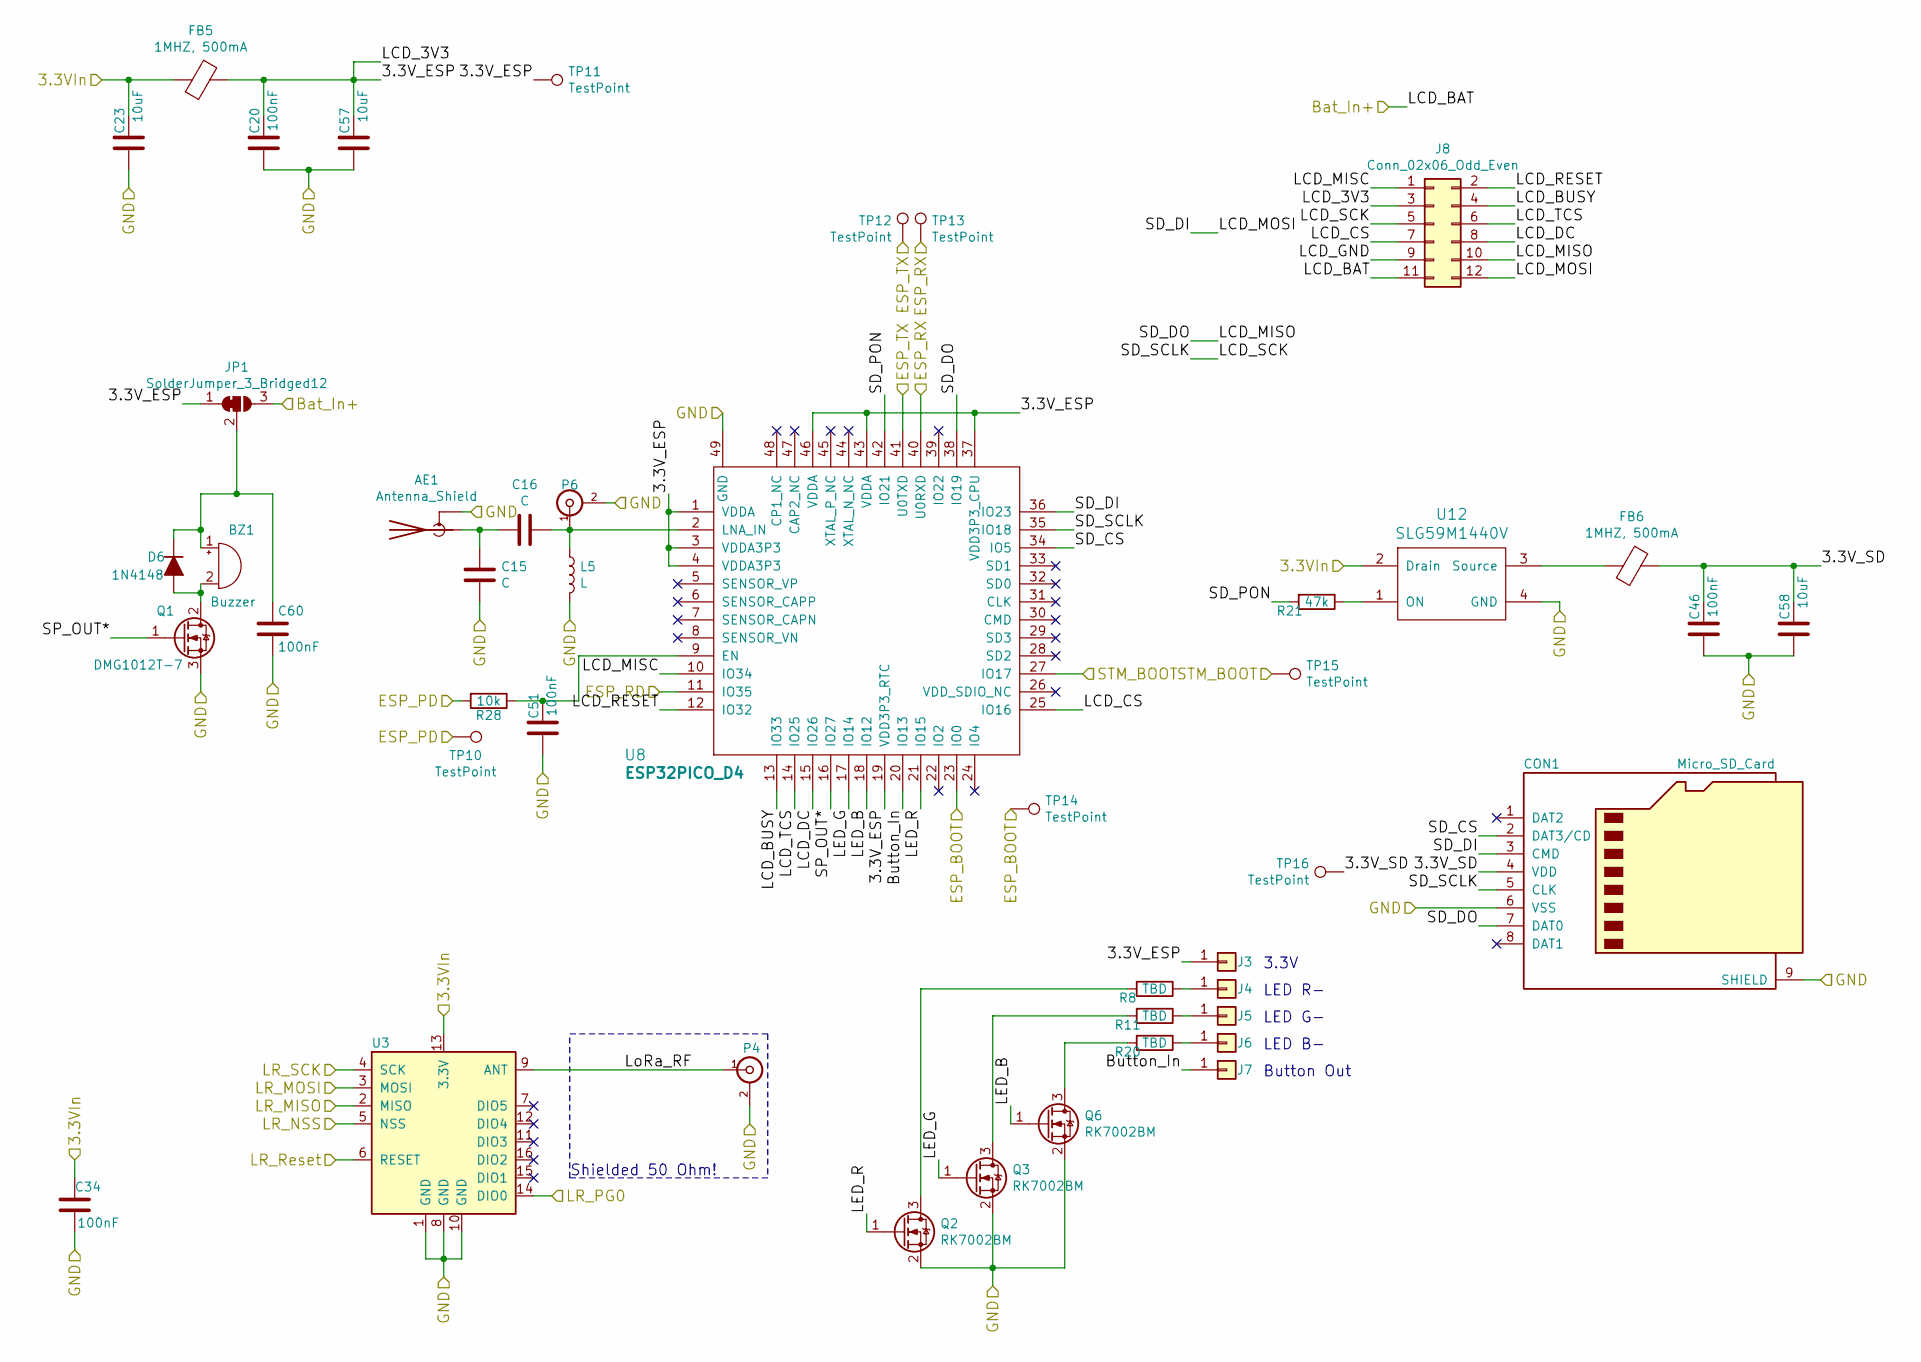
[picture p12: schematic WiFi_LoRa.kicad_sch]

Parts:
AE1: Antenna_Shield; Proant440; Digikey Nr 1532-1001-1-ND
BZ1: Buzzer; CUI_CMT-5023S-SMT; Digikey Nr 102-3743-1-ND
C15, C16: C; C_0402_1005Metric; Digikey Nr TBD (HF)
C20, C34, C46, C51, C60: 100nF; C_0603_1608Metric; Digikey Nr 1276-1000-1-ND
C23, C57, C58: 10uF; C_0603_1608Metric; Digikey Nr 478-10766-1-ND
CON1: Micro_SD_Card; microSD_HC_Wuerth_693072010801; Digikey Nr 732-3820-1-ND
D6: 1N4148; D_SOD-523; Digikey Nr 1N4148XTPMSCT-ND
FB5, FB6: 1MHZ, 500mA; L_0603_1608Metric; Digikey Nr 445-2205-1-ND
J3, J4, J5, J6, J7: Conn_01x01; 2108693-4; Digikey Nr A118885CT-ND
J8: Conn_02x06_Odd_Even; PinHeader_2x06_P1.27mm_Vertical_SMD; Digikey Nr S9012E-06-ND
JP1: SolderJumper_3_Bridged12; SolderJumper-3_P1.3mm_Bridged12_RoundedPad1.0x1.5mm; Digikey Nr NA
L5: L; L_0402_1005Metric; Digikey Nr TBD (HF)
P4, P6: A-1JB (U.FL); U.FL_SMD_Amp; Digikey Nr ARF1579CT-ND
Q1: DMG1012T-7; TSOT-23; Digikey Nr DMG1012T-7DICT-ND
Q2, Q3, Q6: RK7002BM; SOT-23; Digikey Nr RK7002BMT116CT-ND
R8, R11, R20: TBD; R_0603_1608Metric; Digikey Nr TBD
R21: 47k; R_0603_1608Metric; Digikey Nr 311-47.0KHRCT-ND
R28: 10k; R_0603_1608Metric; Digikey Nr 311-10.0KHRCT-ND
TP10, TP11, TP12, TP13, TP14, TP15, TP16: TestPoint; TestPoint_Pad_D1.5mm
U3: RFM95W-868S2; HOPERF_RFM9XW_SMD
U8: ESP32PICO_D4; QFN-48-1EP_7x7mm_Pitch0.5mm; Digikey Nr 1904-1029-1-ND
U12: SLG59M1440V; STDFN-4; Digikey Nr 1827-1058-1-ND

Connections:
+3V3: C23.2, C34.2, FB5.2, U3.13 (3.3V), U12.2 (Drain); also elsewhere on the board
+BATT: J8.11, JP1.3 (B); also elsewhere on the board
/Nucleo/STM_BOOT: TP15.1, U8.27 (IO17); also elsewhere on the board
/WiFi_LoRa/3.3V_ESP: C20.2, C57.2, FB5.1, J3.1, J8.3, JP1.1 (A), TP11.1, U8.1 (VDDA), U8.3 (VDDA3P3), U8.4 (VDDA3P3), U8.19 (VDD3P3_RTC), U8.37 (VDD3P3_CPU), U8.43 (VDDA), U8.46 (VDDA)
/WiFi_LoRa/3.3V_SD: C46.2, C58.2, CON1.4 (VDD), FB6.1, TP16.1
/WiFi_LoRa/Button_In: J7.1, U8.20 (IO13)
/WiFi_LoRa/ESP_BOOT: TP14.1, U8.23 (IO0); also elsewhere on the board
/WiFi_LoRa/ESP_PD: R28.2, TP10.1; also elsewhere on the board
/WiFi_LoRa/ESP_RD: U8.11 (IO35); also elsewhere on the board
/WiFi_LoRa/ESP_RX: TP13.1, U8.40 (U0RXD); also elsewhere on the board
/WiFi_LoRa/ESP_TX: TP12.1, U8.41 (U0TXD); also elsewhere on the board
/WiFi_LoRa/LCD_BUSY: J8.4, U8.13 (IO33)
/WiFi_LoRa/LCD_CS: J8.7, U8.25 (IO16)
/WiFi_LoRa/LCD_DC: J8.8, U8.15 (IO26)
/WiFi_LoRa/LCD_GND: J8.9
/WiFi_LoRa/LCD_MISC: J8.1, U8.10 (IO34)
/WiFi_LoRa/LCD_MISO: CON1.7 (DAT0), J8.10, U8.38 (IO19)
/WiFi_LoRa/LCD_MOSI: CON1.3 (CMD), J8.12, U8.36 (IO23)
/WiFi_LoRa/LCD_RESET: J8.2, U8.12 (IO32)
/WiFi_LoRa/LCD_SCK: CON1.5 (CLK), J8.5, U8.35 (IO18)
/WiFi_LoRa/LCD_TCS: J8.6, U8.14 (IO25)
/WiFi_LoRa/LED_B: Q6.1 (G), U8.18 (IO12)
/WiFi_LoRa/LED_G: Q3.1 (G), U8.17 (IO14)
/WiFi_LoRa/LED_R: Q2.1 (G), U8.21 (IO15)
/WiFi_LoRa/LR_MISO: U3.2 (MISO); also elsewhere on the board
/WiFi_LoRa/LR_MOSI: U3.3 (MOSI); also elsewhere on the board
/WiFi_LoRa/LR_NSS: U3.5 (NSS); also elsewhere on the board
/WiFi_LoRa/LR_PG0: U3.14 (DIO0); also elsewhere on the board
/WiFi_LoRa/LR_Reset: U3.6 (RESET); also elsewhere on the board
/WiFi_LoRa/LR_SCK: U3.4 (SCK); also elsewhere on the board
/WiFi_LoRa/LoRa_RF: P4.1 (In), U3.9 (ANT)
/WiFi_LoRa/SD_CS: CON1.2 (DAT3/CD), U8.34 (IO5)
/WiFi_LoRa/SD_PON: R21.2, U8.42 (IO21)
/WiFi_LoRa/SP_OUT*: Q1.1 (G), U8.16 (IO27)
GND: AE1.2 (Shield), C15.1, C20.1, C23.1, C34.1, C46.1, C51.1, C57.1, C58.1, C60.2, CON1.6 (VSS), CON1.9 (SHIELD), L5.2, P4.2 (Ext), P6.2 (Ext), Q1.3 (S), Q2.2 (S), Q3.2 (S), Q6.2 (S), U3.1 (GND), U3.8 (GND), U3.10 (GND), U8.49 (GND), U12.4 (GND); also elsewhere on the board
unnamed: AE1.1 (A), C15.2, C16.2
unnamed: BZ1.1 (-), C60.1, D6.1 (K), JP1.2 (C)
unnamed: BZ1.2 (+), D6.2 (A), Q1.2 (D)
unnamed: C16.1, L5.1, P6.1 (In), U8.2 (LNA_IN)
unnamed: C51.2, R28.1, U8.9 (EN)
unnamed: FB6.2, U12.3 (Source)
unnamed: J4.1, R8.1
unnamed: J5.1, R11.1
unnamed: J6.1, R20.1
unnamed: Q2.3 (D), R8.2
unnamed: Q3.3 (D), R11.2
unnamed: Q6.3 (D), R20.2
unnamed: R21.1, U12.1 (ON)

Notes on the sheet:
LED B-
Shielded 50 Ohm!
3.3V
Button Out
LED G-
LED R-

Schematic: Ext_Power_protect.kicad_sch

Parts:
C39: 100nF 50V; C_0603_1608Metric; Digikey Nr 1292-1392-1-ND
C40: 10uF 50V; C_1206_3216Metric; Digikey Nr 1276-6736-1-ND
C41: 22nF; C_0603_1608Metric; Digikey Nr 399-1280-1-ND
C42, C43: 22uF; C_0805_2012Metric; Digikey Nr 1276-6780-1-ND
D7: D_Schottky_ALT; D_SOD-123F; Digikey Nr MBR230LSFT1GOSCT-ND
FB2: 1MHZ, 500mA; L_0603_1608Metric; Digikey Nr 445-2205-1-ND
L2: 4.7uH; L_Taiyo-Yuden_NR-50xx; Digikey Nr 587-2407-1-ND
R31: NA/0; R_0603_1608Metric; Digikey Nr 311-0.0GRCT-ND
R32: 10k; R_0603_1608Metric; Digikey Nr 311-10.0KHRCT-ND
R33: 47k; R_0603_1608Metric; Digikey Nr 311-47.0KHRCT-ND
U13: TS30041/11; QFN-16-1EP_3x3mm_Pitch0.5mm; Digikey Nr TS30041-M000QFNRCT-ND
W20: TEST_1P; TestPoint_Pad_D1.0mm; Digikey Nr NA

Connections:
/Ext_Power_protect/EN_DCDCin: U13.9 (EN); also elsewhere on the board
/Ext_Power_protect/PG_DCDCin: U13.8 (PG); also elsewhere on the board
/Ext_Power_protect/VSW: C41.2, D7.1 (K), L2.1, U13.1 (VSW), U13.12 (VSW), U13.13 (VSW), U13.16 (VSW)
/Ext_Vin: FB2.2; also elsewhere on the board
/Reg_5V: C42.2, C43.2, L2.2, R31.1, R33.1, W20.1; also elsewhere on the board
GND: C39.1, C40.2, C42.1, C43.1, D7.2 (A), R32.1, U13.4 (GND), U13.14 (PGND), U13.15 (PGND), U13.17 (GND); also elsewhere on the board
unnamed: C39.2, C40.1, FB2.1, R31.2, U13.2 (VCC), U13.3 (VCC), U13.11 (VCC)
unnamed: C41.1, U13.10 (BST)
unnamed: R32.2, R33.2, U13.5 (FB)
unnamed: U13.6 (NC), U13.7 (NC)

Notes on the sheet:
If TS300x1 not assembled, R = 0 Ohm
max 40V
shielded

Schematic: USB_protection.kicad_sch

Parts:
C49: 680nF; C_0603_1608Metric; Digikey Nr 732-7970-1-ND
FB3, FB4: Ferrite Bead; L_0603_1608Metric; Digikey Nr 732-1593-1-ND
R35, R36: 22; R_0603_1608Metric; Digikey Nr 311-22.0HRCT-ND
U14: IP4220CZ6; SC-74; Digikey Nr 1727-3578-1-ND
W21: TEST_1P; TestPoint_Pad_D1.0mm; Digikey Nr NA

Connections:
+5VP: FB3.2, W21.1; also elsewhere on the board
/USB_Protection/Din+: R36.1, U14.1 (IO1); also elsewhere on the board
/USB_Protection/Din-: R35.1, U14.3 (IO2); also elsewhere on the board
/USB_Protection/Dout+: R36.2; also elsewhere on the board
/USB_Protection/Dout-: R35.2; also elsewhere on the board
/USB_Protection/ID_In: U14.4 (IO3); also elsewhere on the board
/USB_Protection/VBus_In: FB4.1, U14.5 (Vp); also elsewhere on the board
GND: C49.1, U14.2 (GND); also elsewhere on the board
unnamed: C49.2, FB3.1, FB4.2

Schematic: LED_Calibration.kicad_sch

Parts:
D5: LED; LED_0603_1608Metric; Digikey Nr 492-1949-1-ND
R38: 1k; R_0603_1608Metric; Digikey Nr 311-1.00KHRCT-ND
TP23: TestPoint; TestPoint_Pad_D1.5mm

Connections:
/Nucleo/LED_Trigger(PA8)*: R38.2; also elsewhere on the board
GND: D5.1 (K); also elsewhere on the board
unnamed: D5.2 (A), R38.1, TP23.1

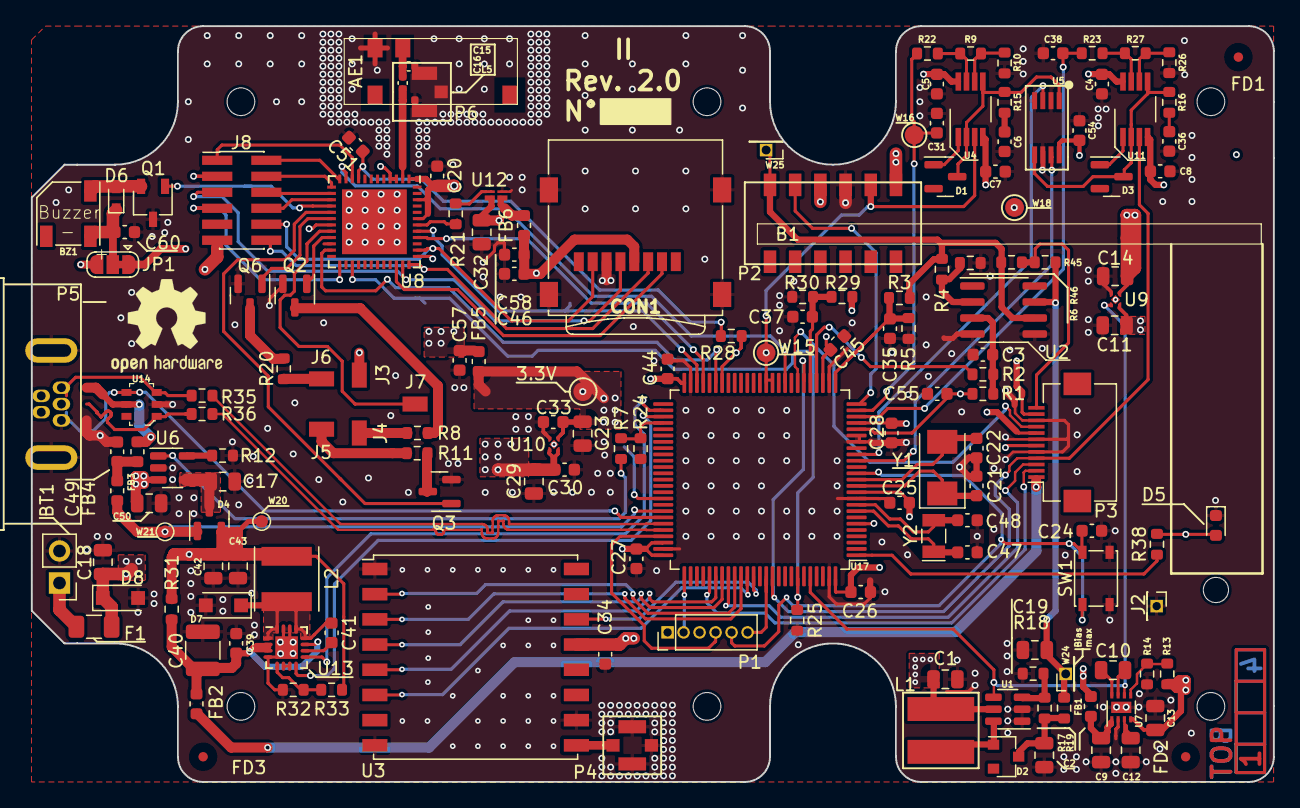
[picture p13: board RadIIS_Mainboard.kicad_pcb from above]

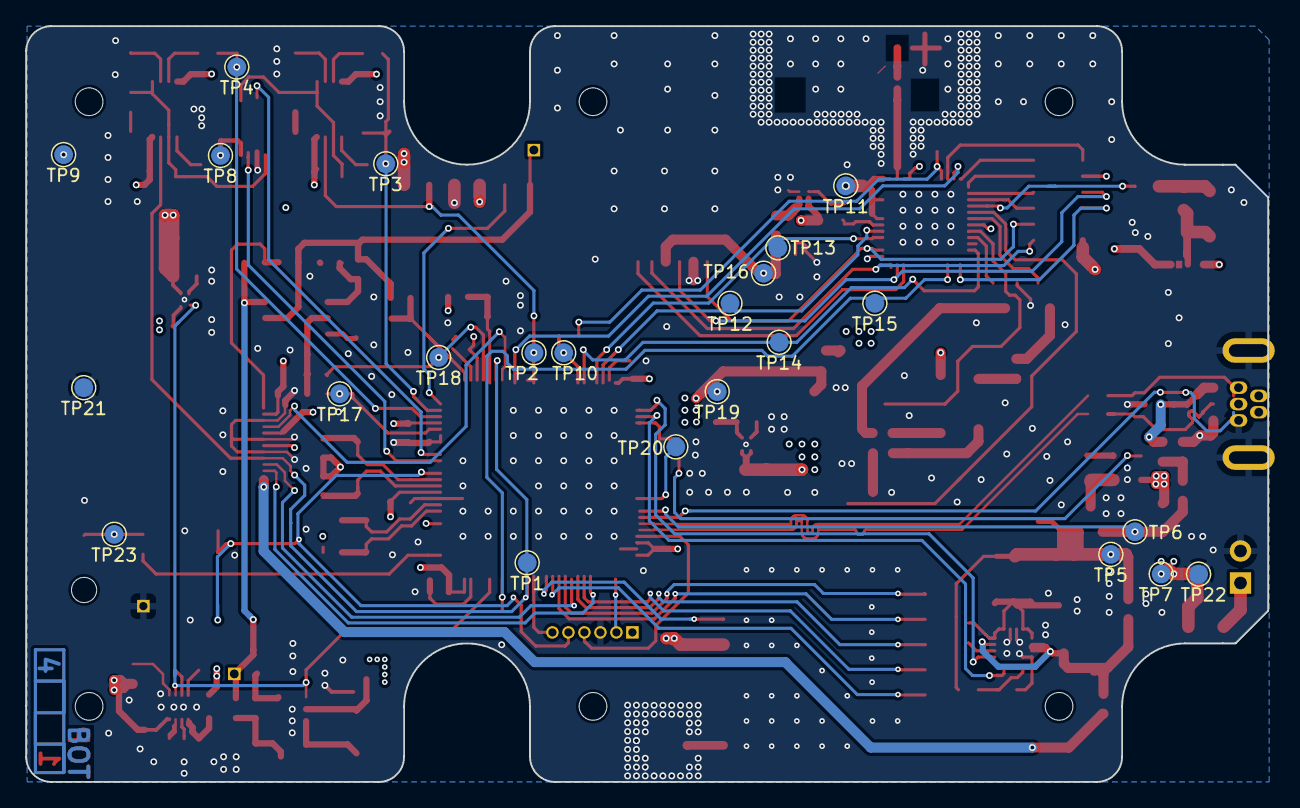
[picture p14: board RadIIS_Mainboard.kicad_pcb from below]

Board: 4 copper layers, 98.6 x 60.0 mm, 187 parts (23 on the bottom side), 120 nets.

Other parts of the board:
FD1, FD2, FD3: Fiducial_0.75mm_Mask2.25mm

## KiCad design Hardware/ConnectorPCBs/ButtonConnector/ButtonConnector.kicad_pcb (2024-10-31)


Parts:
SW1: SW_Push_LED; MBP16_RGB_PCB
TP1, TP2, TP3, TP4, TP5: Pad; TestPoint_Pad_2.0x2.0mm

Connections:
unnamed: SW1.1, TP3.1
unnamed: SW1.2, SW1.3, TP5.1
unnamed: SW1.4 (R), TP2.1
unnamed: SW1.5 (G), TP1.1
unnamed: SW1.6 (B), TP4.1



Board: 2 copper layers, 12.0 x 12.0 mm, 6 parts (5 on the bottom side), 5 nets.
